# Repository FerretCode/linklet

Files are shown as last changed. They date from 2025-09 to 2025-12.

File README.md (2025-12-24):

# linklet

A modular, LoRa enabled sensor bus

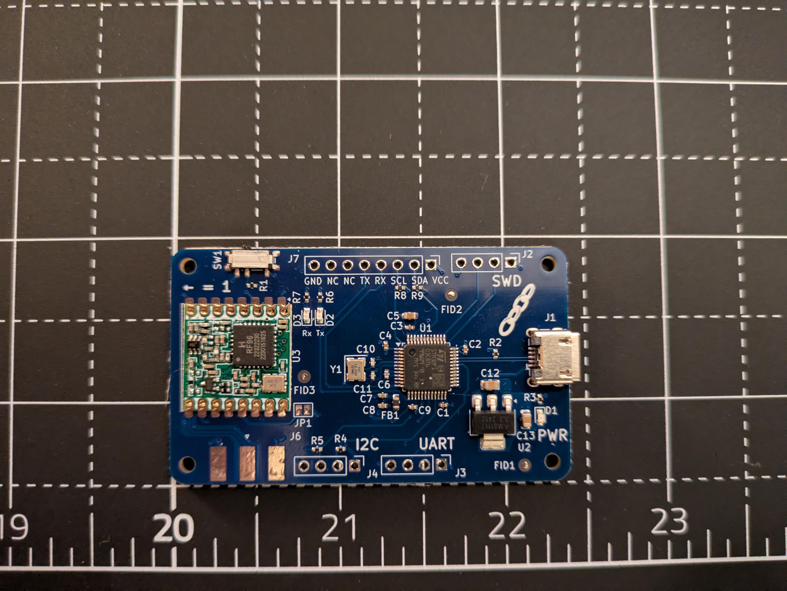
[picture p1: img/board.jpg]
Linklet Board


## Overview

- Linklet is an custom PCB design with an STM32 and RFM69HCW LoRa modules for sensing and IoT operations
- The base board exposes 1x UART and 1x I2C interface for basic sensors
- The board is powered over micro-USB
- Linklet also exposes a 1x8 pin socket connector for carrying daughter boards
    - The connector has 1x UART and 1x I2C interface for daughter boards
    - It makes it easy for swapping out different sensor arrays on the fly

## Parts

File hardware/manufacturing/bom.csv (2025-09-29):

Comment | Designator | Footprint | Supplier and ref
Conn_Coaxial | J6 | SMA_Molex_73251-1153_EdgeMount_Horizontal | C43302011
100n | C1,C4,C3,C9,C2 | C_0402_1005Metric | C309458
Conn_01x08_Socket | J7 | PinHeader_1x08_P2.54mm_Vertical | C9900212703
1k5 | R8,R3,R9,R4,R2,R5 | R_0402_1005Metric | C25867
10u | C5 | C_0603_1608Metric | C96446
1k | R7,R6 | R_0402_1005Metric | C49652832
USB_B_Micro | J1 | USB_Micro-B_Wuerth_629105150521 | C2894326
1u | C7,C8 | C_0402_1005Metric | C52923
Conn_01x04_Pin | J2,J4,J3 | PinHeader_1x04_P2.54mm_Vertical | C5116483
STM32F103C8T6 | U1 | LQFP-48_7x7mm_P0.5mm | C8734
SW_SPDT | SW1 | SW_SPDT_PCM12 | C221841
10n | C6 | C_0402_1005Metric | C3855387
AMS1117-3.3 | U2 | SOT-223-3_TabPin2 | C6186
16MHz | Y1 | Crystal_SMD_3225-4Pin_3.2x2.5mm | C112972
10p | C11,C10 | C_0402_1005Metric | C106199
22u | C13,C12 | C_0805_2012Metric | C452754
10k | R1 | R_0402_1005Metric | C1002
220R | FB1 | L_0603_1608Metric | C66810
RED | D1,D2,D3 | LED_0603_1608Metric | C965798

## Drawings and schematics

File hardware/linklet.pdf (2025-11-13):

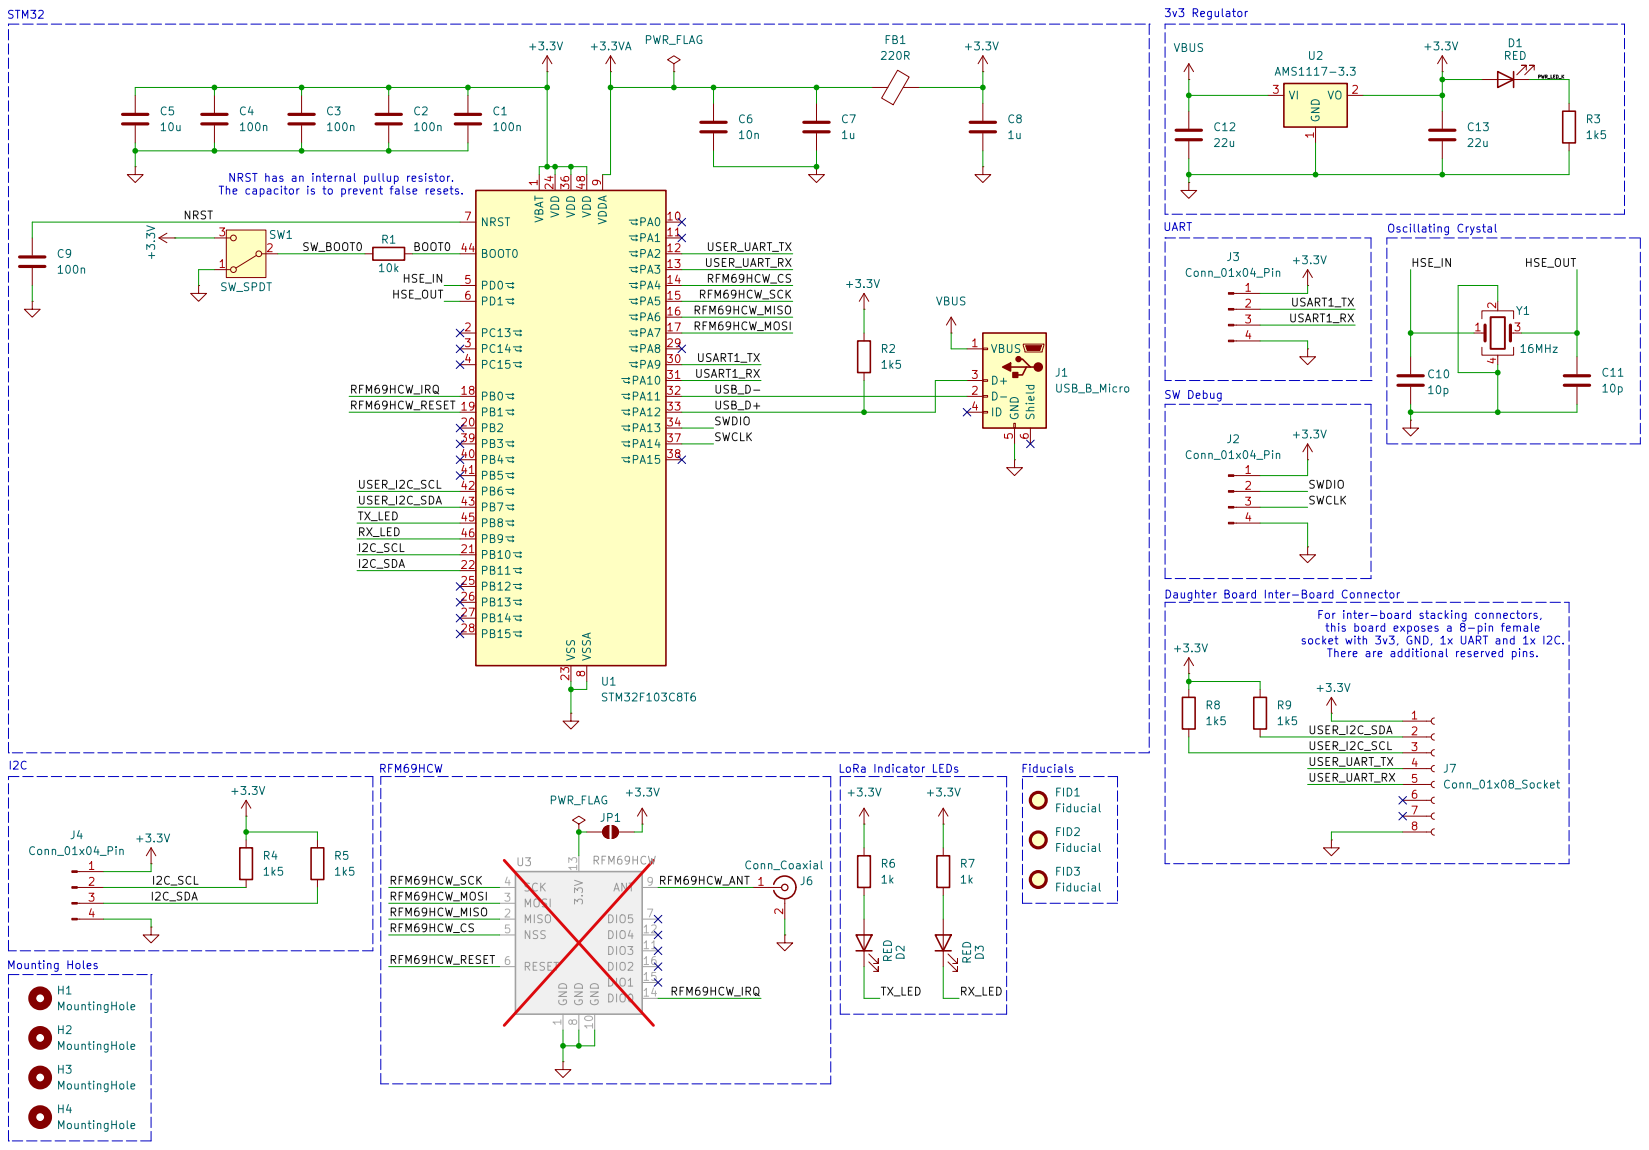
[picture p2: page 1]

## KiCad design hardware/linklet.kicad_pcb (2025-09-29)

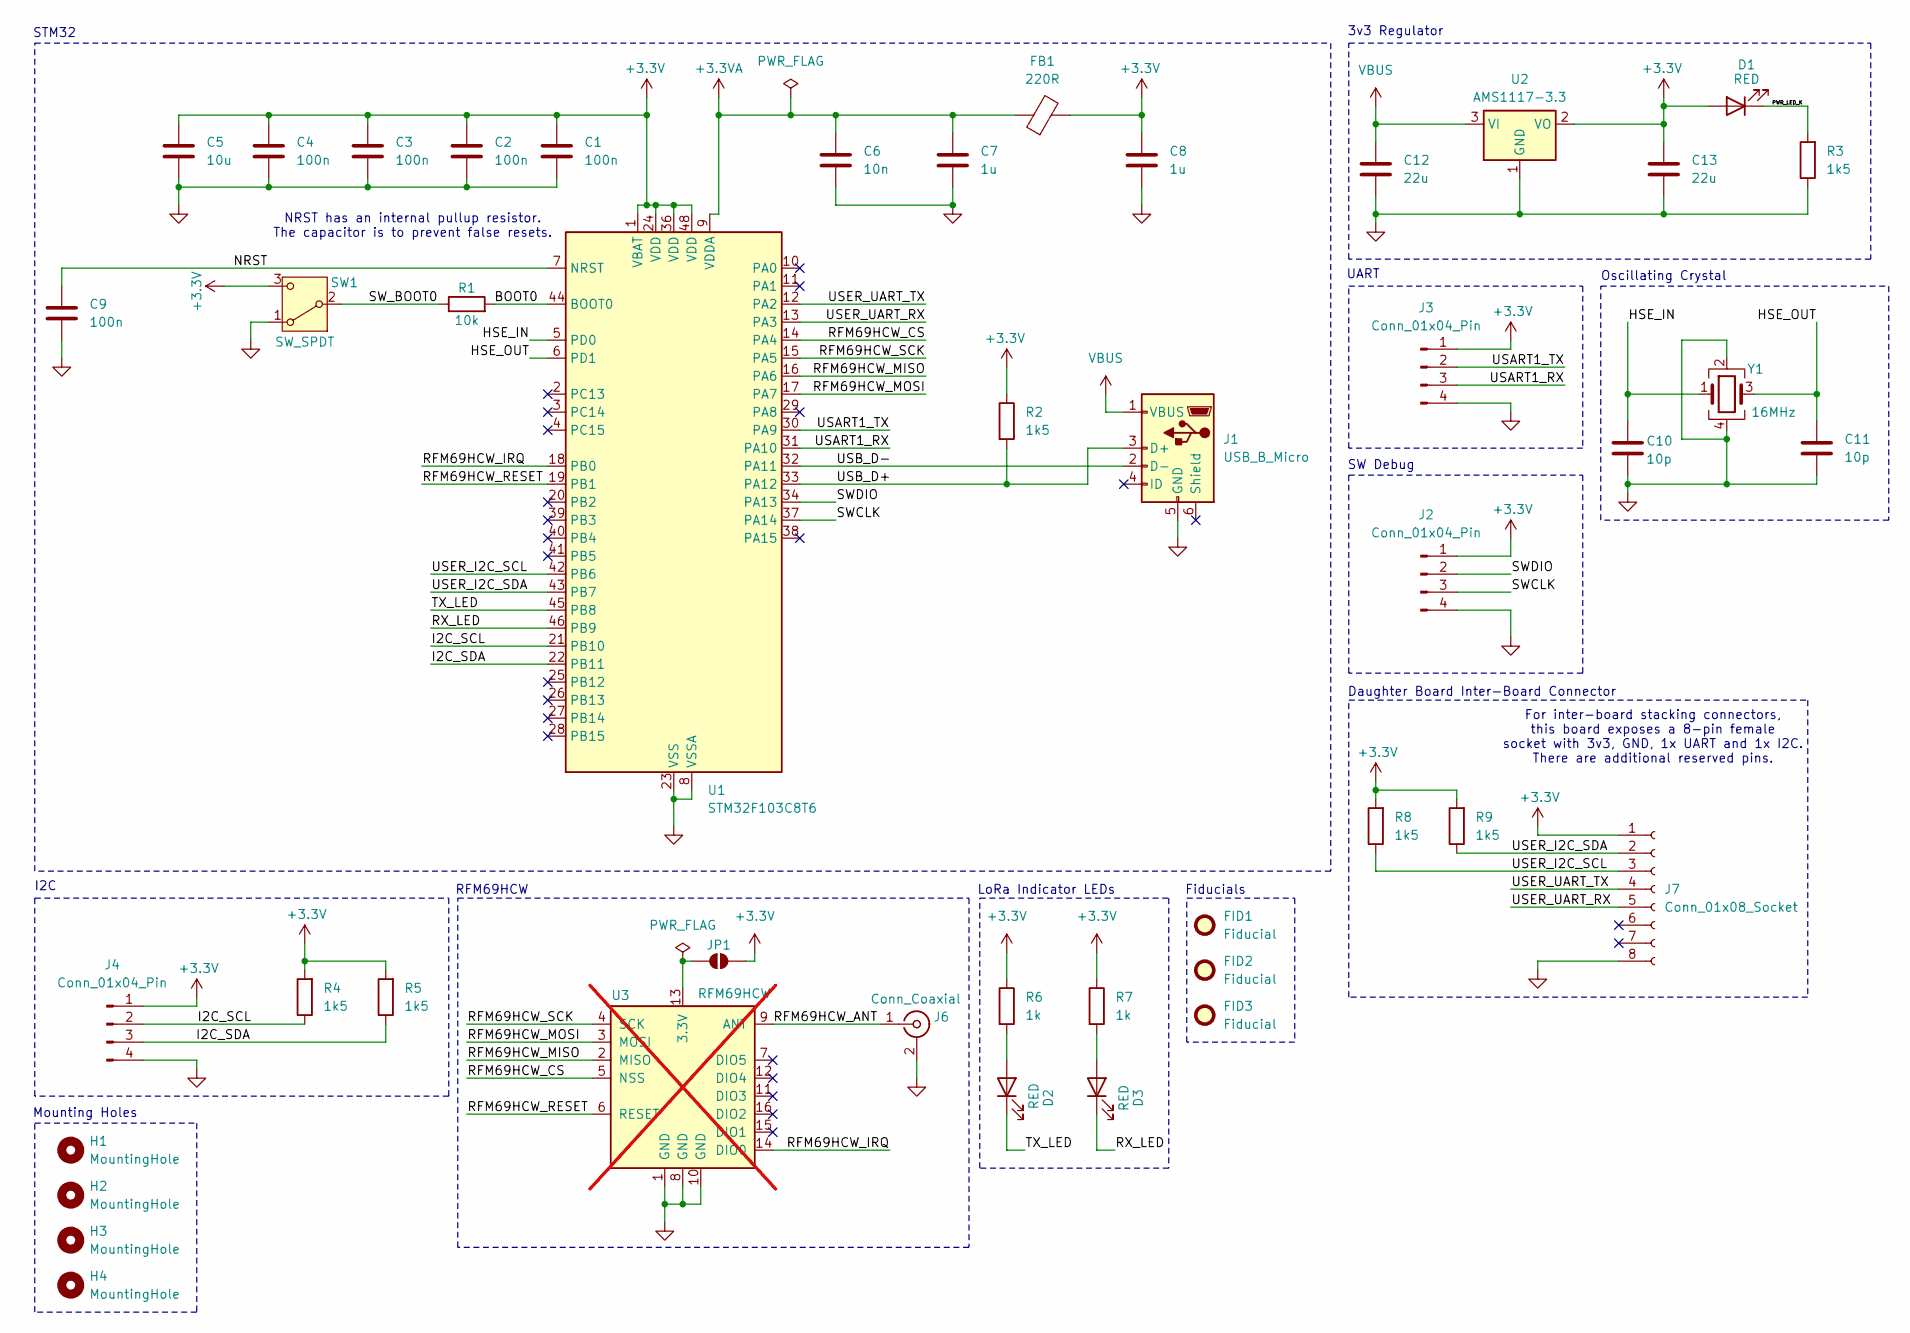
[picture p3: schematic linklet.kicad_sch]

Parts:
C1, C2, C3, C4, C9: 100n; C_0402_1005Metric; LCSC PN C309458
C5: 10u; C_0603_1608Metric; LCSC PN C96446
C6: 10n; C_0402_1005Metric; LCSC PN C3855387
C7, C8: 1u; C_0402_1005Metric; LCSC PN C52923
C10, C11: 10p; C_0402_1005Metric; LCSC PN C106199
C12, C13: 22u; C_0805_2012Metric; LCSC PN C452754
D1, D2, D3: RED; LED_0603_1608Metric; LCSC PN C965798
FB1: 220R; L_0603_1608Metric; LCSC PN C66810
FID1, FID2, FID3: Fiducial; Fiducial_1mm_Mask2mm
H1, H2, H3, H4: MountingHole; MountingHole_2.2mm_M2
J1: USB_B_Micro; USB_Micro-B_Wuerth_629105150521; LCSC PN C2894326
J2, J3, J4: Conn_01x04_Pin; PinHeader_1x04_P2.54mm_Vertical; LCSC PN C5116483
J6: Conn_Coaxial; SMA_Molex_73251-1153_EdgeMount_Horizontal; LCSC PN C43302011
J7: Conn_01x08_Socket; PinHeader_1x08_P2.54mm_Vertical; LCSC PN C9900212703
JP1: SolderJumper_2_Open; SolderJumper-2_P1.3mm_Open_Pad1.0x1.5mm
R1: 10k; R_0402_1005Metric; LCSC PN C1002
R2, R3, R4, R5, R8, R9: 1k5; R_0402_1005Metric; LCSC PN C25867
R6, R7: 1k; R_0402_1005Metric; LCSC PN C49652832
SW1: SW_SPDT; SW_SPDT_PCM12; LCSC PN C221841
U1: STM32F103C8T6; LQFP-48_7x7mm_P0.5mm; LCSC PN C8734
U2: AMS1117-3.3; SOT-223-3_TabPin2; LCSC PN C6186
U3: RFM69HCW; HOPERF_RFM9XW_SMD; not fitted
Y1: 16MHz; Crystal_SMD_3225-4Pin_3.2x2.5mm; LCSC PN C112972

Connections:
+3.3V: C1.1, C2.1, C3.1, C4.1, C5.1, C8.1, C13.1, D1.2 (A), FB1.2, J2.1, J3.1, J4.1, J7.1, JP1.1 (A), R2.1, R4.2, R5.2, R6.1, R7.1, R8.2, R9.2, SW1.3 (C), U1.1 (VBAT), U1.24 (VDD), U1.36 (VDD), U1.48 (VDD), U2.2 (VO)
+3.3VA: C6.1, C7.1, FB1.1, U1.9 (VDDA)
/BOOT0: R1.2, U1.44 (BOOT0)
/HSE_IN: C10.1, U1.5 (PD0), Y1.1
/HSE_OUT: C11.1, U1.6 (PD1), Y1.3
/I2C_SCL: J4.2, R4.1, U1.21 (PB10)
/I2C_SDA: J4.3, R5.1, U1.22 (PB11)
/NRST: C9.1, U1.7 (NRST)
/PWR_LED_K: D1.1 (K), R3.2
/RFM69HCW_ANT: J6.1 (In), U3.9 (ANT)
/RFM69HCW_CS: U1.14 (PA4), U3.5 (NSS)
/RFM69HCW_IRQ: U1.18 (PB0), U3.14 (DIO0)
/RFM69HCW_MISO: U1.16 (PA6), U3.2 (MISO)
/RFM69HCW_MOSI: U1.17 (PA7), U3.3 (MOSI)
/RFM69HCW_RESET: U1.19 (PB1), U3.6 (RESET)
/RFM69HCW_SCK: U1.15 (PA5), U3.4 (SCK)
/RX_LED: D3.1 (K), U1.46 (PB9)
/SWCLK: J2.3, U1.37 (PA14)
/SWDIO: J2.2, U1.34 (PA13)
/SW_BOOT0: R1.1, SW1.2 (B)
/TX_LED: D2.1 (K), U1.45 (PB8)
/USART1_RX: J3.3, U1.31 (PA10)
/USART1_TX: J3.2, U1.30 (PA9)
/USB_D+: J1.3 (D+), R2.2, U1.33 (PA12)
/USB_D-: J1.2 (D-), U1.32 (PA11)
/USER_I2C_SCL: J7.3, R8.1, U1.42 (PB6)
/USER_I2C_SDA: J7.2, R9.1, U1.43 (PB7)
/USER_UART_RX: J7.5, U1.13 (PA3)
/USER_UART_TX: J7.4, U1.12 (PA2)
GND: C1.2, C2.2, C3.2, C4.2, C5.2, C6.2, C7.2, C8.2, C9.2, C10.2, C11.2, C12.2, C13.2, J1.5 (GND), J2.4, J3.4, J4.4, J6.2 (Ext), J7.8, R3.1, SW1.1 (A), U1.8 (VSSA), U1.23 (VSS), U1.35 (VSS), U1.47 (VSS), U2.1 (GND), U3.1 (GND), U3.8 (GND), U3.10 (GND), Y1.2, Y1.4
unnamed: D2.2 (A), R6.2
unnamed: D3.2 (A), R7.2
unnamed: JP1.2 (B), U3.13 (3.3V)
VBUS: C12.1, J1.1 (VBUS), U2.3 (VI)

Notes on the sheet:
Daughter Board Inter-Board Connector
SW Debug
Mounting Holes
NRST has an internal pullup resistor. The capacitor is to prevent false resets.
UART
STM32
For inter-board stacking connectors, this board exposes a 8-pin female socket with 3v3, GND, 1x UART and 1x I2C. There are additional reserved pins.
Fiducials
3v3 Regulator
Oscillating Crystal
I2C
RFM69HCW
LoRa Indicator LEDs

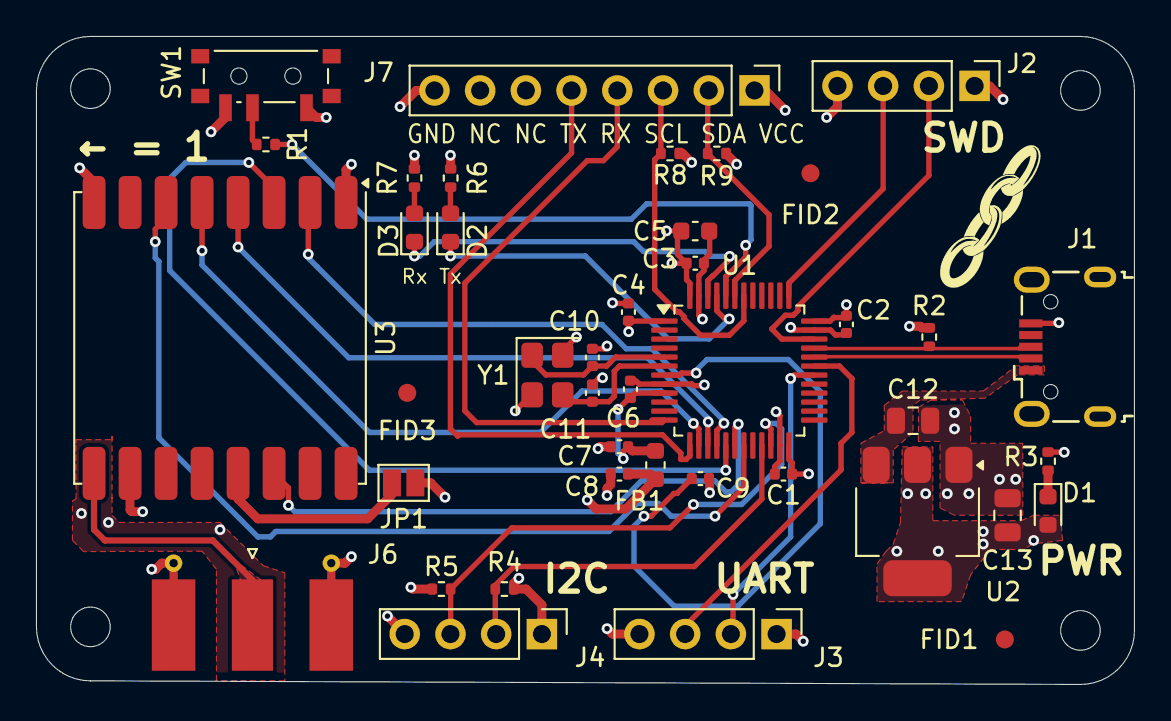
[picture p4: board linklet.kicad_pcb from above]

Board: 4 copper layers, 61.0 x 36.0 mm, 45 parts (0 on the bottom side), 34 nets.

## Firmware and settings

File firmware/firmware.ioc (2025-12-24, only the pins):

Mcu.UserName=STM32F103C8Tx
PA10.Signal=USART1_RX
PA11.Signal=USB_DM
PA12.Signal=USB_DP
PA2.Signal=USART2_TX
PA3.Signal=USART2_RX
PA9.Signal=USART1_TX
PB10.Signal=I2C2_SCL
PB11.Signal=I2C2_SDA
PB6.Signal=I2C1_SCL
PB7.Signal=I2C1_SDA
PD0-OSC_IN.Signal=RCC_OSC_IN
PD1-OSC_OUT.Signal=RCC_OSC_OUT

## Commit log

2025-09-22 add project
    [linklet.kicad_pcb, linklet.kicad_sch]
2025-09-22 update silkscreen
    [linklet.kicad_pcb]
2025-09-22 switch to using grounded coplanar waveguide for RF feed line
    [linklet.kicad_pcb]
2025-09-29 add manufacturing files
    [bom.csv, designators.csv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]
2025-12-24 bootstrap firmware
    [bom.csv, designators.csv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]
